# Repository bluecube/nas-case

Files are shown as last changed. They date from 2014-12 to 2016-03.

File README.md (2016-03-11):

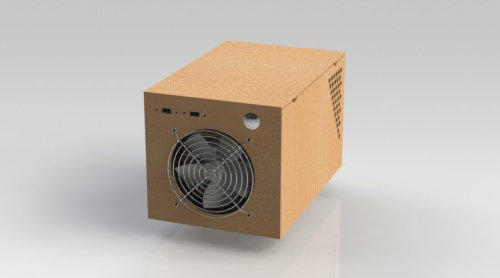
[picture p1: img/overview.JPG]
Overview render

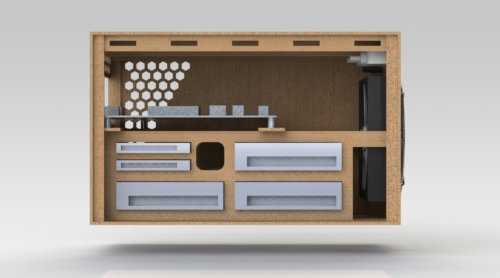
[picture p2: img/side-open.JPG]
Side render with opened wall

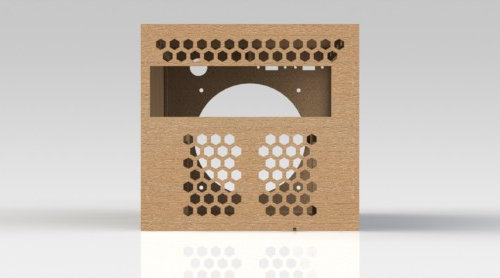
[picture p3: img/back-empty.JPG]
Back render

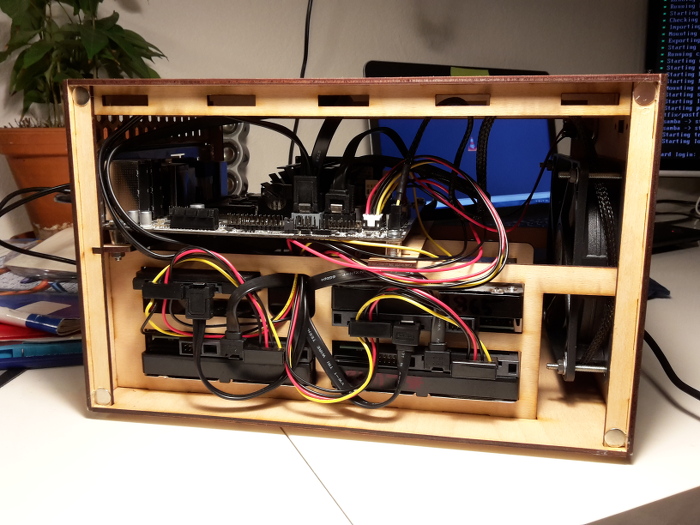
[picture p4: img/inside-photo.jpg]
Inside photo

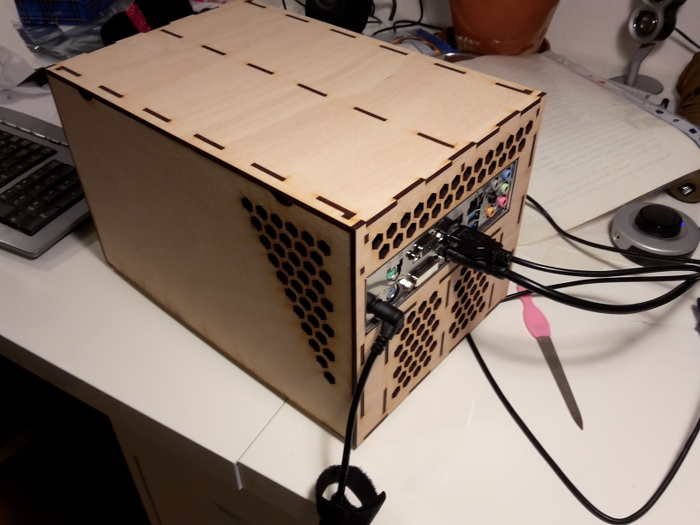
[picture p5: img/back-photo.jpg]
Back photo


This is a laser cut case for a small diy NAS server I've built.
I started designing this when I realized that there isn't any case that would have the features that I wanted (small,
mounts for several 3.5" HDDs).
As a bonus it came out a bit cheaper than the cases I was considering buying.
I've had it lasered from 3mm beech plywood, when assembled and glued together it feels light and solid.

- Holds a mini-itx mainboard, three 3.5" drives and two 2.5" SSDs.
- Has no room for internal power supply, it is intended for use with external power brick; either use a board like ASRock Q1900DC-ITX, or a picoPSU power supply.
- Front panel of the case has a large 120mm fan, two USB ports and a power button. No LEDs (I want a server, not a christmas tree).
- Side walls are attached with flat neodymium magnets.

In case you are building this case (or modifying it, or something), let me know and tell me what you think about it.
Other than the SolidWorks models, there also is [a dwg file](https://github.com/bluecube/nas-case/blob/master/img/laser.DWG?raw=true).
It is possible that you will need to modify the front panel to mount your USB ports and power switch, I've used USBs from a PCI bracket and a shiny chromed outdoor doorbell button.

The model in this repository is the version I've built, but there are some upgrades I'd do if I made another of these cases:

- The box is pretty cramped when fitting the mainboard in. The ceiling should be on magnets for easier access as well.
  This would require redesigning the whole top part, but shouldn't be too complicated.
- There is more than one way to fit the parts together (especially switching left-right sides of the drive frame and back wall)
  and only one of them is the correct one.
  The locking notches should be assymetrical, so that the only way to fit the box together is the correct one.
- Maybe think of some way to simplify cable management?
- The drive slots should be 1mm-1.5mm larger than the drives and the edges should be covered in foam tape for tighter fit and reduced vibrations.

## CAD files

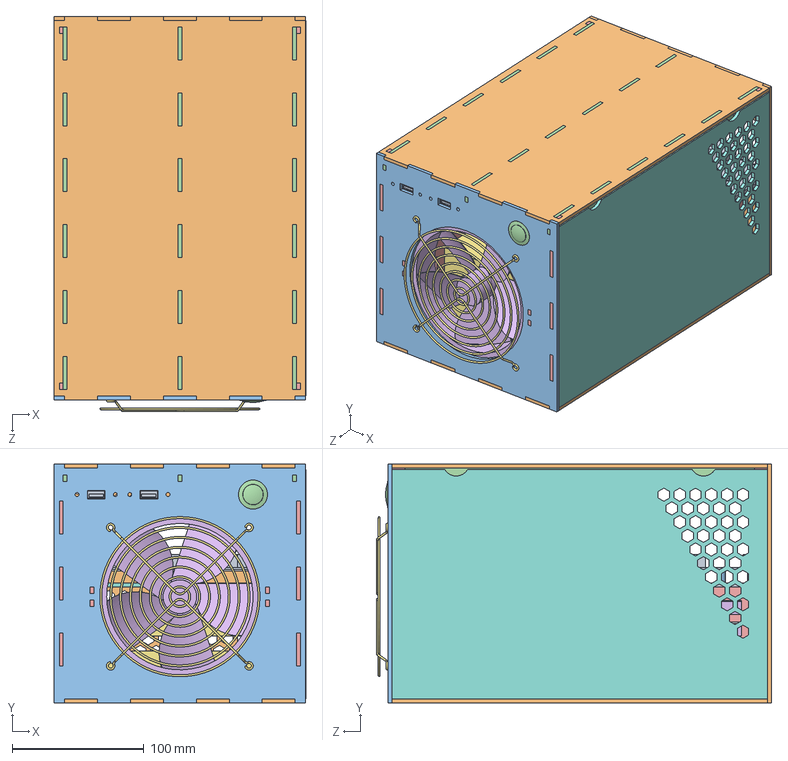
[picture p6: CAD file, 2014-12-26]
nas-case.SLDASM
191.2 x 181.0 x 299.9 mm
mini-itx
floor x 2
front
button
drive-beam x 3
25drive x 2
35drive x 3
board-support-front
board-support-back
back
spacer x 4
ceiling-bar x 3
vertical-bar x 4
120fan
120fan_cover
side
usb_plug x 2
magnet x 8

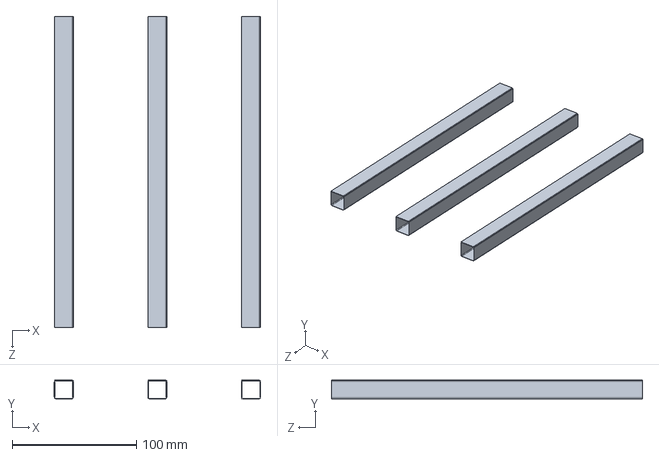
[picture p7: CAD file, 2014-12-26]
frame-level.SLDASM
165.6 x 15.0 x 250.0 mm
beam x 3

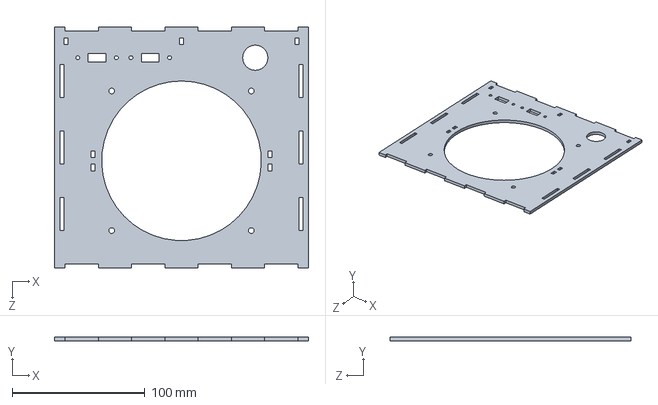
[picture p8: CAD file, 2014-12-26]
front.SLDPRT
191.0 x 3.00 x 181.0 mm

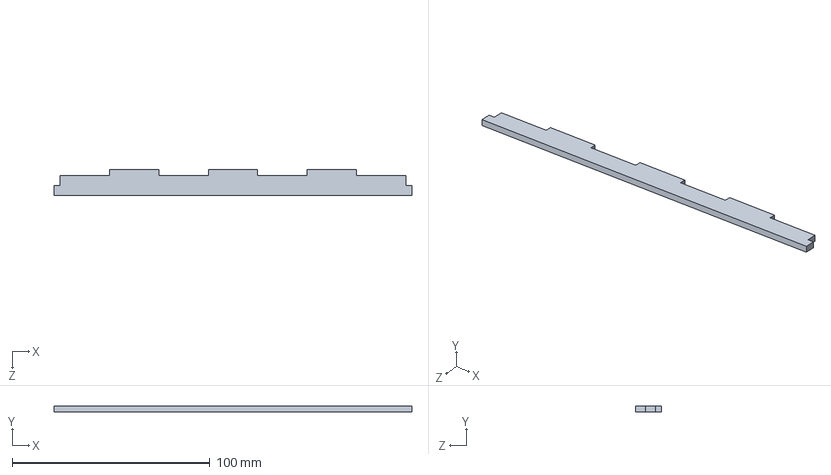
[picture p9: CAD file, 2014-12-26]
vertical-bar.SLDPRT
181.0 x 3.00 x 13.0 mm

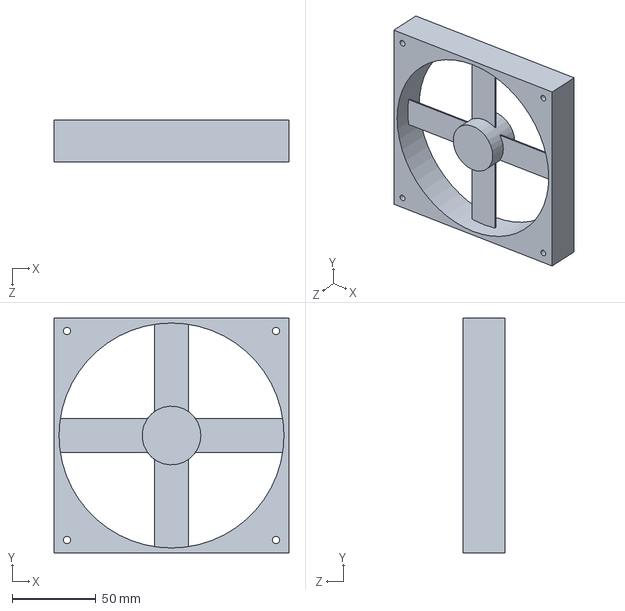
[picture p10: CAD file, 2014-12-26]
140fan.SLDPRT
140.0 x 140.0 x 25.0 mm

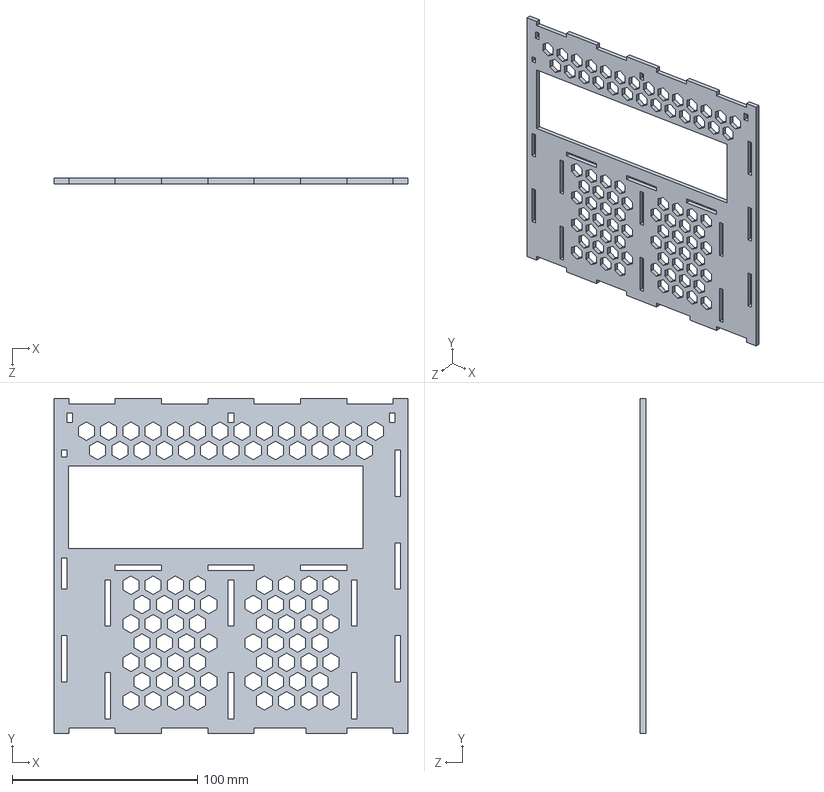
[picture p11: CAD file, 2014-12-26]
back.SLDPRT
191.0 x 181.0 x 3.00 mm

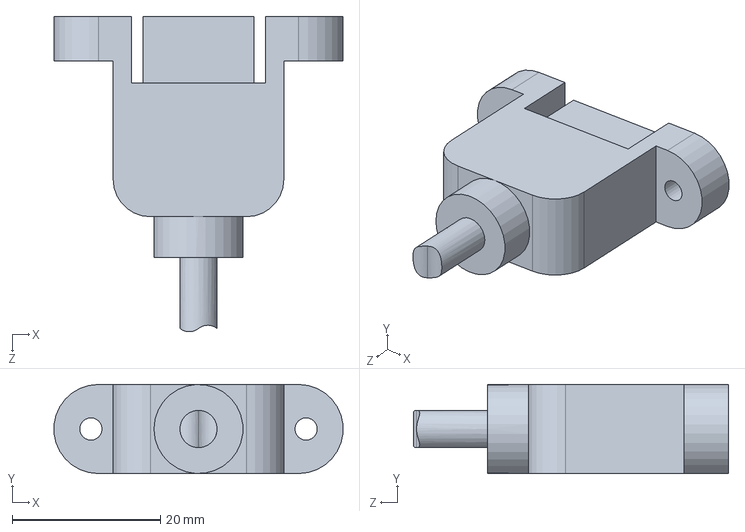
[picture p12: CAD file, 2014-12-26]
usb_plug.SLDPRT
38.9 x 12.0 x 42.5 mm

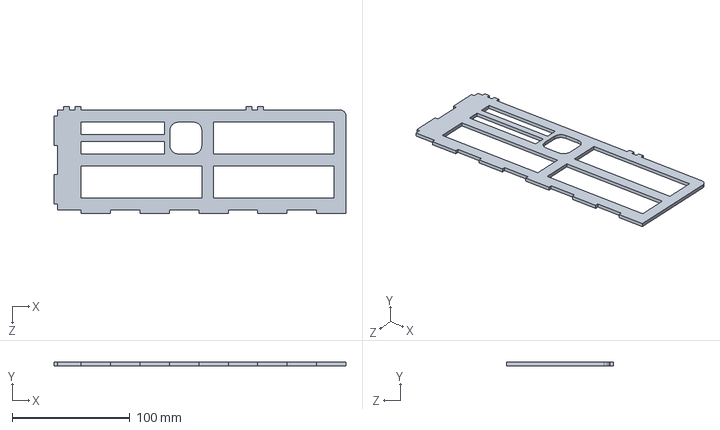
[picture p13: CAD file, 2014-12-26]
drive-beam.SLDPRT
248.0 x 3.00 x 91.0 mm

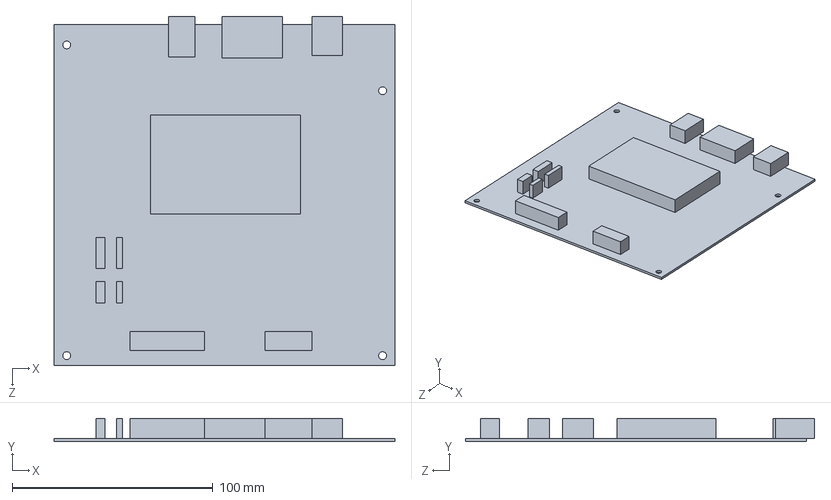
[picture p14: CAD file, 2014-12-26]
mini-itx.SLDPRT
170.0 x 11.6 x 174.0 mm

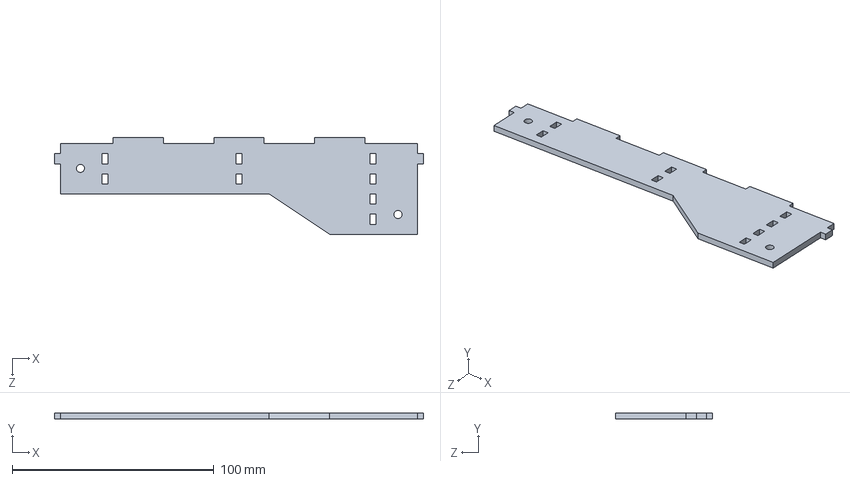
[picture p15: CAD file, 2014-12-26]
board-support-back.SLDPRT
183.0 x 3.00 x 48.0 mm

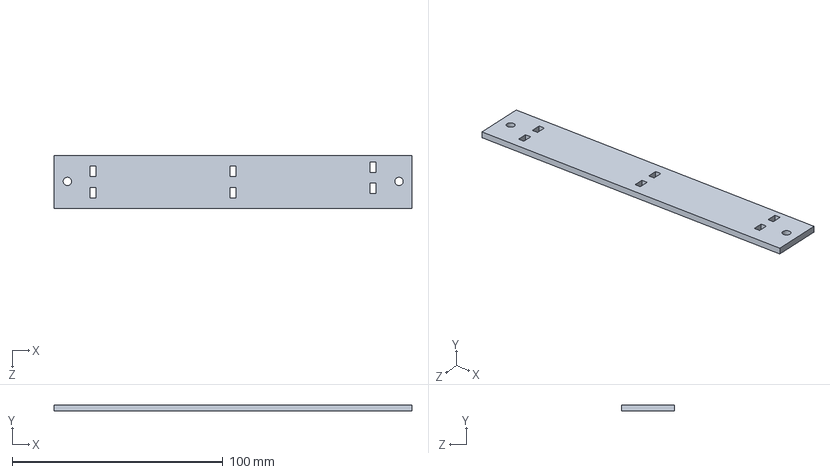
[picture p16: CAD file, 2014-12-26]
board-support-front.SLDPRT
170.0 x 3.00 x 25.0 mm

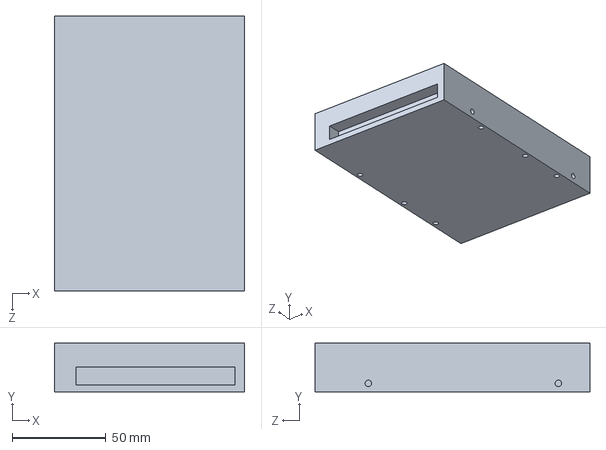
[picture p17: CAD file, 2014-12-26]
35drive.SLDPRT
101.6 x 26.1 x 147.0 mm

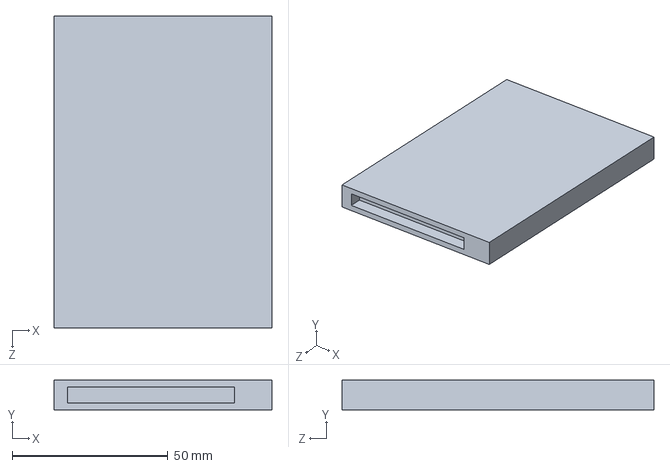
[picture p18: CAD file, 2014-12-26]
25drive.SLDPRT
69.8 x 9.50 x 100.0 mm

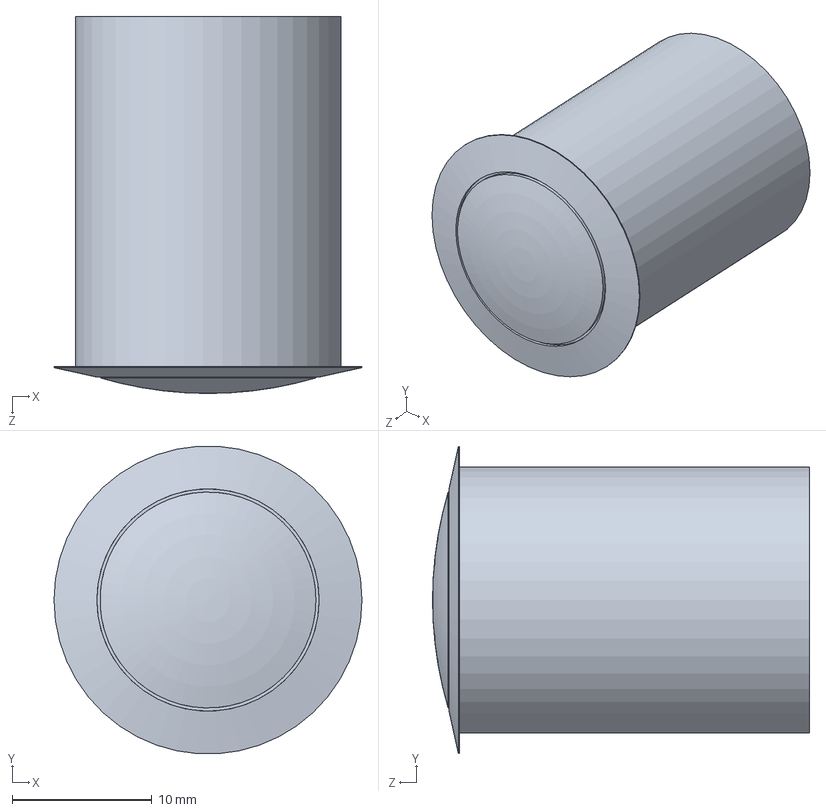
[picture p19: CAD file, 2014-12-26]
button.SLDPRT
22.0 x 21.9 x 26.9 mm

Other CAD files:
img/laser.DWG
spacer.SLDPRT
floor.SLDPRT
ceiling-bar.SLDPRT
120fan.SLDPRT
120fan_cover.SLDPRT
beam.SLDPRT
laser.SLDDRW
magnet.SLDPRT
side.SLDPRT

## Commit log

2014-12-26 Initial commit. Model V1.
    [120fan.SLDPRT, 120fan_cover.SLDPRT, 140fan.SLDPRT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]
2014-12-26 dwg file.
    [laser.DWG]
2015-06-27 Added photos.
    [laser.DWG]
